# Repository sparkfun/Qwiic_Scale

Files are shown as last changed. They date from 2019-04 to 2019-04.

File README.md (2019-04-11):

SparkFun Qwiic Scale
========================================

SparkFun Qwiic Scale (https://www.sparkfun.com/products/15242)

[*SparkFun Qwiic Scale (SEN-15242)*](https://www.sparkfun.com/products/15242)

This repo is the hardware repo for the Qwiic Scale.

Strain gauges are a lot of fun to play with but they often need complex conditioning and conversion ICs. Qwiic Scale takes care of all the hardware and software concerns and gets you measuring weight!

We've written an extensive Arduino library to make reading a load cell over I2C a breeze. Calibrate, get weight, and you're set.

This board is one of our many [Qwiic](https://www.sparkfun.com/qwiic) compatible boards! Simply plug and go. No soldering, no figuring out which is SDA or SCL, and no voltage regulation or translation required!

SparkFun labored with love to create this code. Feel like supporting open source hardware? 
Buy a [breakout board](https://www.sparkfun.com/products/15242) from SparkFun!

Repository Contents
-------------------

* **/Documents** - Datasheets
* **/Hardware** - Eagle design files (.brd, .sch)

Documentation
--------------
* **[Qwiic Scale Hookup Guide](https://learn.sparkfun.com/tutorials/qwiic-scale-hookup-guide)** - Hookup guide for the Qwiic Scale
* **[Installing an Arduino Library Guide](https://learn.sparkfun.com/tutorials/installing-an-arduino-library)** - Basic information on how to install an Arduino library.
* **[Arduino Library](https://github.com/sparkfun/SparkFun_Qwiic_Scale_NAU7802_Arduino_Library)**

License Information
-------------------

This product is _**open source**_! 

If you have any questions or concerns on licensing, please contact techsupport@sparkfun.com.

Please use, reuse, and modify these files as you see fit. Please maintain attribution to SparkFun Electronics and release any derivative under the same license.

Distributed as-is; no warranty is given.

- Your friends at SparkFun.

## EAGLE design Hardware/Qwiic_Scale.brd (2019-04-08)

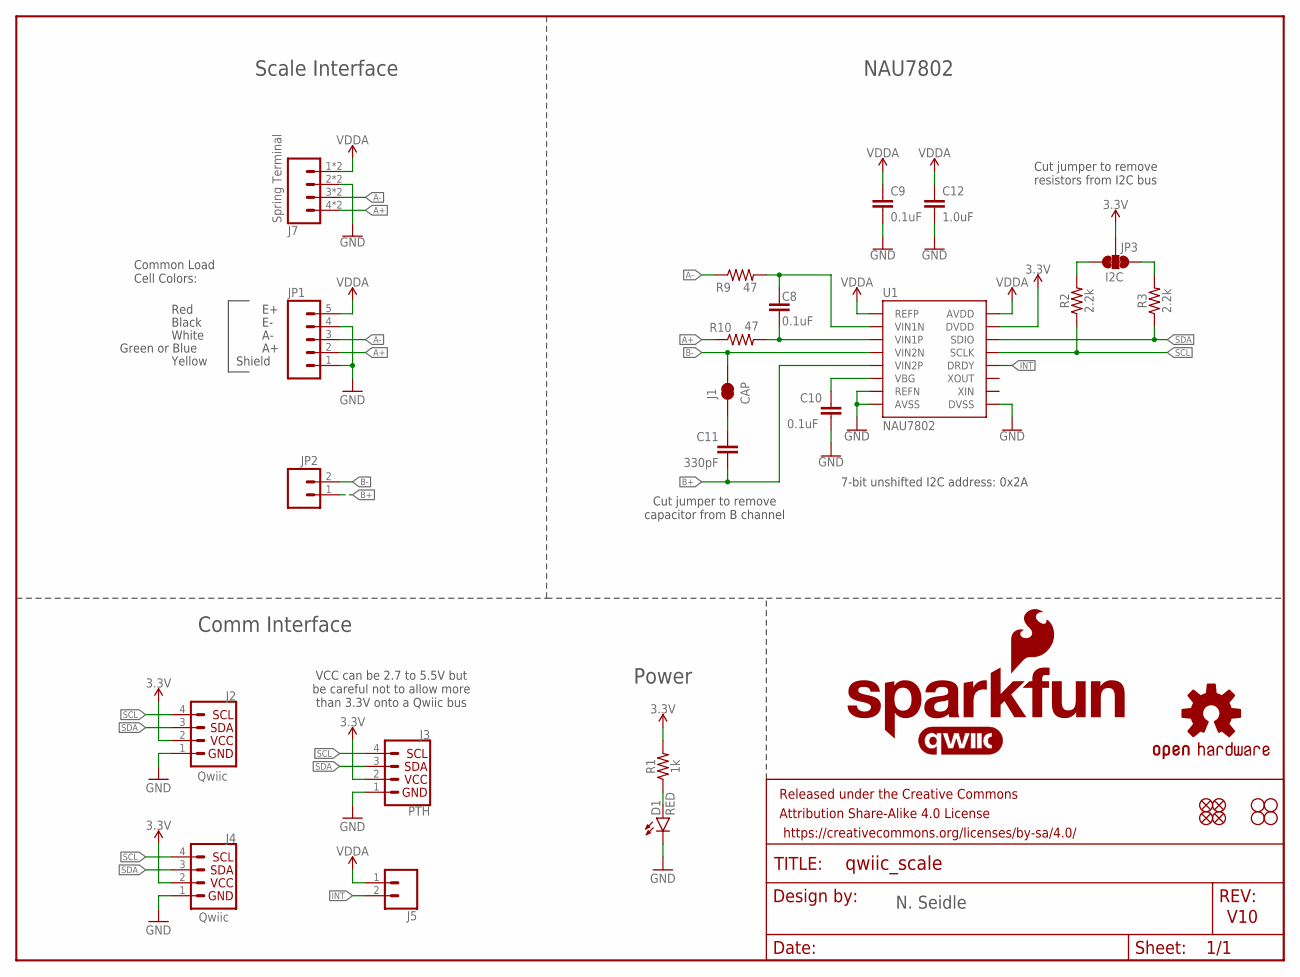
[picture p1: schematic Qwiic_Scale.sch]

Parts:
C8, C9, C10: 0.1uF; 0603
C11: 330pF; 0603
C12: 1.0uF; 0603
D1: RED; LED-0603
FRAME1: FRAME-LETTER; CREATIVE_COMMONS
J1: CAP; SMT-JUMPER_2_NC_TRACE_SILK
J2, J4: Qwiic; JST04_1MM_RA
J3: PTH; 1X04_NO_SILK
J5: CONN_021X02_NO_SILK; 1X02_NO_SILK
J7: Spring Terminal; 1X04_SPRING_TERMINAL
JP1: CONN_05NO_SILK; 1X05_NO_SILK
JP2: CONN_021X02_NO_SILK; 1X02_NO_SILK
JP3: I2C; SMT-JUMPER_3_2-NC_TRACE_SILK
JP21, JP61, JP71, JP81: FIDUCIALUFIDUCIAL; MICRO-FIDUCIAL
JP31, JP41, JP91, JP101: STAND-OFF
LOGO1: OSHW-LOGOMINI; OSHW-LOGO-MINI
LOGO2: SFE_LOGO_NAME_FLAME.1_INCH; SFE_LOGO_NAME_FLAME_.1
R1: 1k; 0603
R2, R3: 2.2k; 0603
R9, R10: 47; 0603
U1: NAU7802; SO16
U$16: QWIIC_LOGO_7MM; QWIIC_7MM

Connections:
3.3V: J2.2, J3.2, J4.2, JP3.2, R1.2, U1.15 (DVDD)
A+: J7.4, J7.8 (4), JP1.2, R10.1
A-: J7.3, J7.7 (3), JP1.3, R9.1
B+: C11.2, JP2.1, U1.5 (VIN2P)
B-: J1.2, JP2.2, U1.4 (VIN2N)
GND: C9.2, C10.2, C12.2, D1.C, J2.1, J3.1, J4.1, J7.2, J7.6 (2), JP1.1, JP1.4, U1.7 (REFN), U1.8 (AVSS), U1.9 (DVSS)
INT: J5.2, U1.12 (DRDY)
unnamed: C11.1, J1.1
unnamed: JP3.1, R3.2
unnamed: JP3.3, R2.2
unnamed: D1.A, R1.1
unnamed: C10.1, U1.6 (VBG)
unnamed: C8.2, R10.2, U1.3 (VIN1P)
unnamed: C8.1, R9.2, U1.2 (VIN1N)
SCL: J2.4, J3.4, J4.4, R2.1, U1.13 (SCLK)
SDA: J2.3, J3.3, J4.3, R3.1, U1.14 (SDIO)
VDDA: C9.1, C12.1, J5.1, J7.1, J7.5 (1), JP1.5, U1.1 (REFP), U1.16 (AVDD)

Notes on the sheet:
V10
7-bit unshifted I2C address: 0x2A
Cut jumper to remove resistors from I2C bus
Red
Black
White
Green or Blue
Common Load Cell Colors:
Shield
Yellow
Cut jumper to remove capacitor from B channel
N. Seidle
NAU7802
Comm Interface
Scale Interface
Power
VCC can be 2.7 to 5.5V but be careful not to allow more than 3.3V onto a Qwiic bus

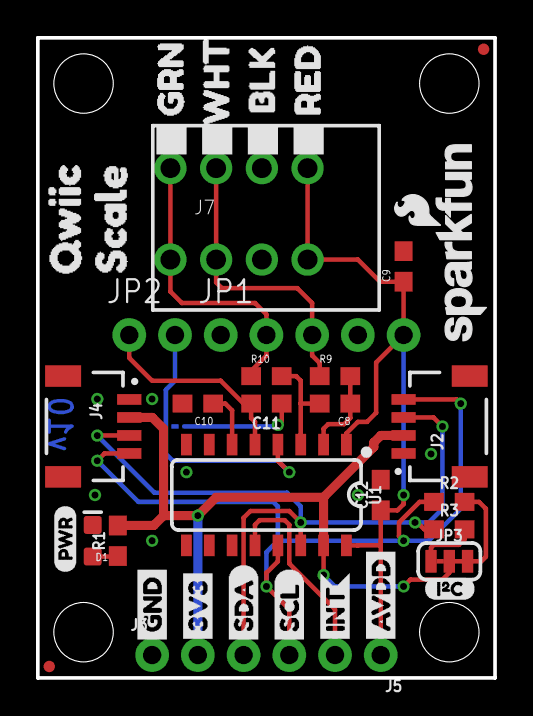
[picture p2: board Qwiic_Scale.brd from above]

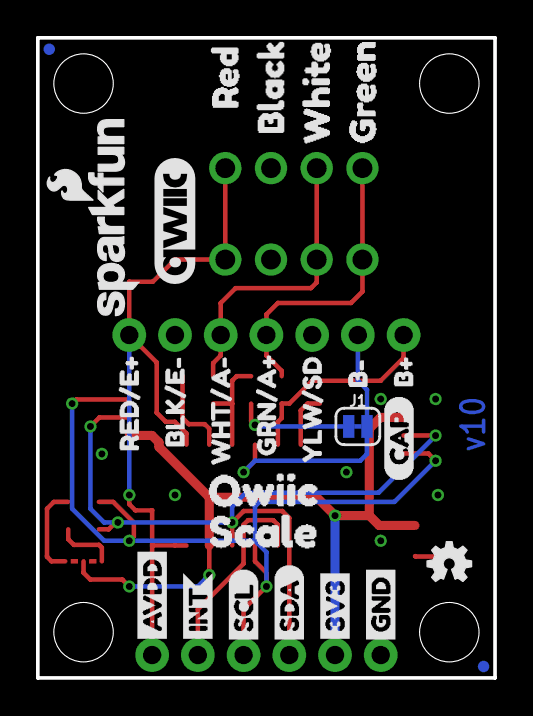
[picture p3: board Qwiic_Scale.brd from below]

Board: 2 copper layers, 25.4 x 35.6 mm, 68 parts (26 on the bottom side), 17 nets.

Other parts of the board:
LOGO3: SFE_LOGO_NAME_FLAME.1_INCH; SFE_LOGO_NAME_FLAME_.1
U$1, U$4: SDA-[)
U$3, U$5: SCL-[)
U$6, U$7: 3V3-04
U$8, U$9: GND-04
U$11: YLW#SD4
U$12: B#11
U$13: B#12
U$14, U$22: QWIIC2
U$15, U$21: INT0
U$17, U$24: SCALE3
U$18: PWR-()-03
U$19: I_SUPER2_C-()-03
U$20: CAP0
U$34: BLK#E#1
U$35: GRN#A#4
U$36, U$45: AVDD4
U$37: BLACK5
U$38: BLK1
U$39: GREEN7
U$40: GRN3
U$41: RED0
U$42: RED4
U$43: WHITE6
U$44: WHT2
U$46: RED#E#2
U$48: WHT#A#3

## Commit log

2019-02-19 Fixing FP on terminal. Adding ignore.
    [Qwiic_Scale.brd, Qwiic_Scale.sch]
2019-02-19 Updating spring terminal. Adding prod IDs. Update readme.
    [Qwiic_Scale.brd, Qwiic_Scale.sch]
2019-02-19 Adding panel
    [Qwiic_Scale-Panel.brd]
2019-02-20 Silk change to terminal. Better ground ties.
    [Qwiic_Scale.brd, Qwiic_Scale.sch]
2019-03-04 Remove examples. Add proto panel. Move firmware to library repo.
    [Qwiic_Scale-Panel.GBL, Qwiic_Scale-Panel.GBO, Qwiic_Scale-Panel.GBS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]
2019-03-05 Divided schematic. Added VDD range.
    [Qwiic_Scale.brd, Qwiic_Scale.sch]
2019-03-07 Update Qwiic logo. Remove old panel files.
    [Qwiic_Scale-Panel.GBL, Qwiic_Scale-Panel.GBO, Qwiic_Scale-Panel.GBS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]
2019-03-07 Change int flag to output
    [Qwiic_Scale.brd]
2019-03-07 Changing int flag to output
    [Qwiic_Scale.brd]
2019-04-08 Remove extraneous wire from schematic
    [Qwiic_Scale.brd, Qwiic_Scale.sch]

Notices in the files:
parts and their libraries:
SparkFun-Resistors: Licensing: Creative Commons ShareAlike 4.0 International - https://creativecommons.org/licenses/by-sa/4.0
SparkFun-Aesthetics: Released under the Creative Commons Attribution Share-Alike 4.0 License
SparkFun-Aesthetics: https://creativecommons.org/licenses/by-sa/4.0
